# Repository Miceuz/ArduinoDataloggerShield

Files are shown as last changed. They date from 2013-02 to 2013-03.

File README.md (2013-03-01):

ArduinoDataloggerShield
=======================

SD card datalogger shield for Arduino with two external voltage references. 

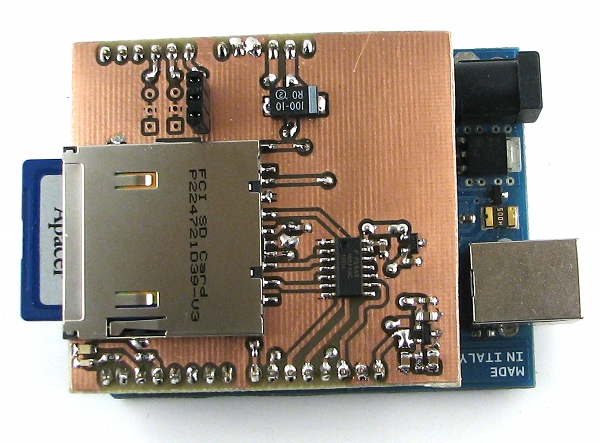
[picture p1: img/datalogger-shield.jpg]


I've made this shield because there were no designs in the wild employing external references - this is usefull feature to have when logging analog voltages.

Features: 
 * 74hc125 buffer for level translation
 * 1.20V voltage reference selectable via solder jumper
 * 2.5V voltage reference selectable via solder jumper
 * red indication led
 * green indication led
 * SD card detection
 * SD card write protection detection

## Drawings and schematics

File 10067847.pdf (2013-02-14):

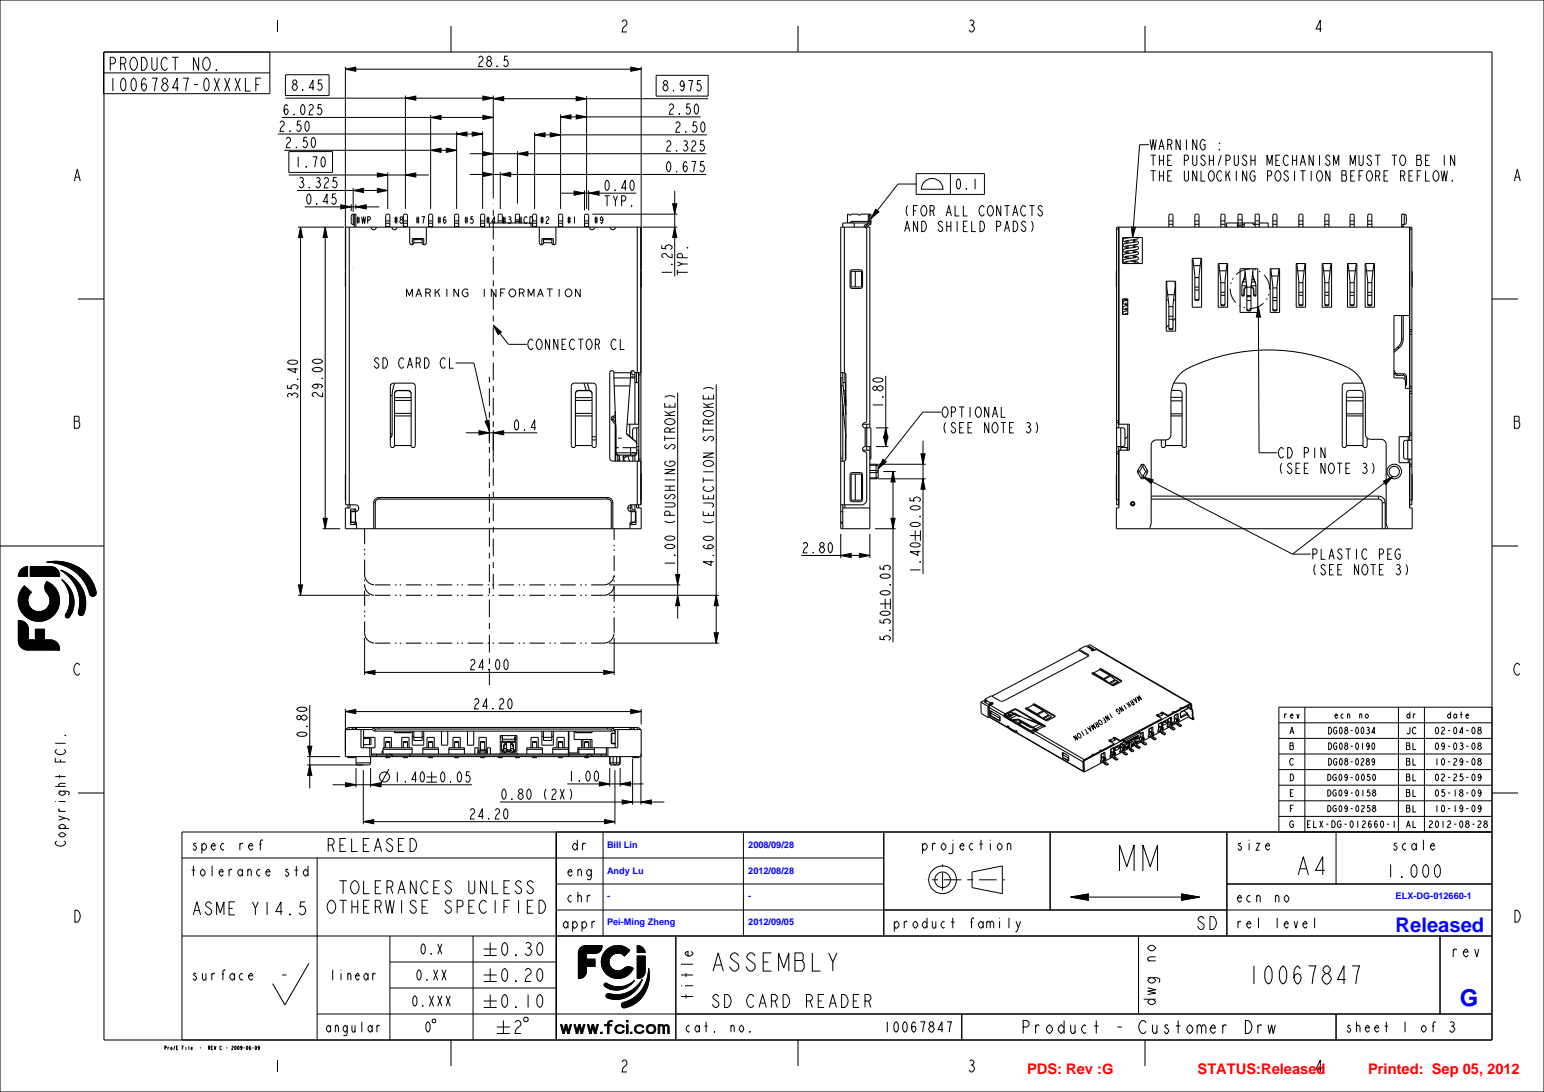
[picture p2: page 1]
Andy Lu; Bill Lin; Released; PDS: Rev :G; STATUS:Released; Printed: Sep 05, 2012

- | | | ELX-DG-012660-1

Pei-Ming Zheng | 2012/09/05

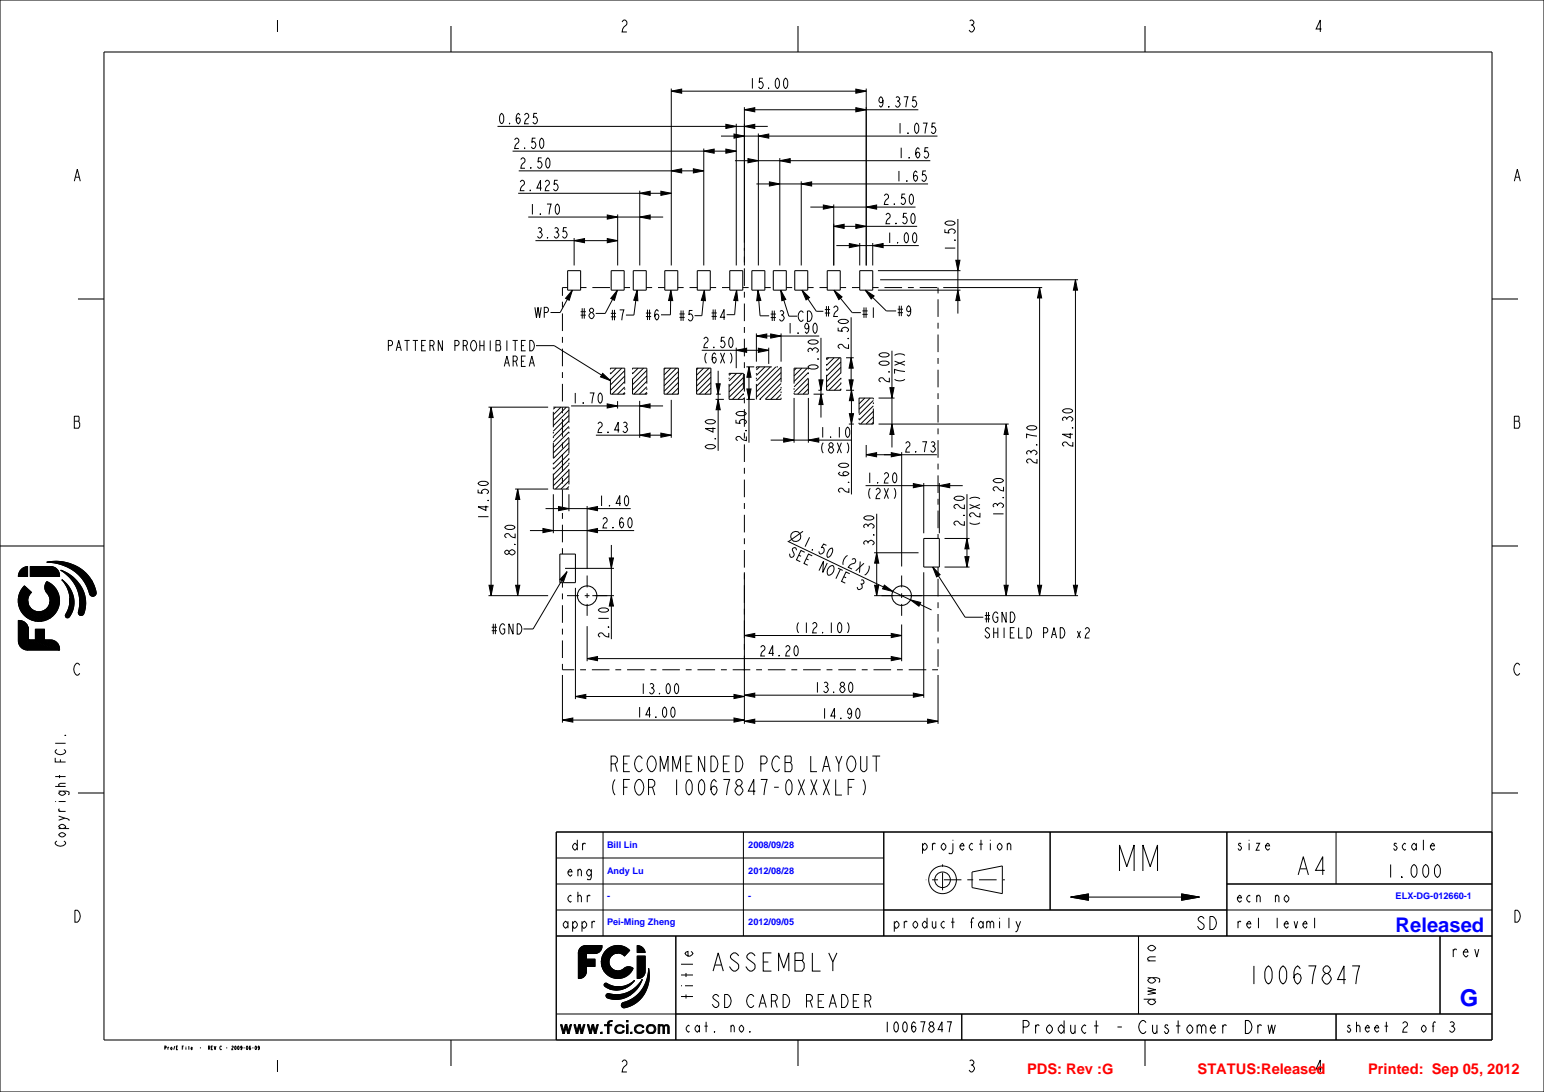
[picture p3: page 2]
Andy Lu; Bill Lin; Released

- | | | | ELX-DG-012660-1

Pei-Ming Zheng | 2012/09/05

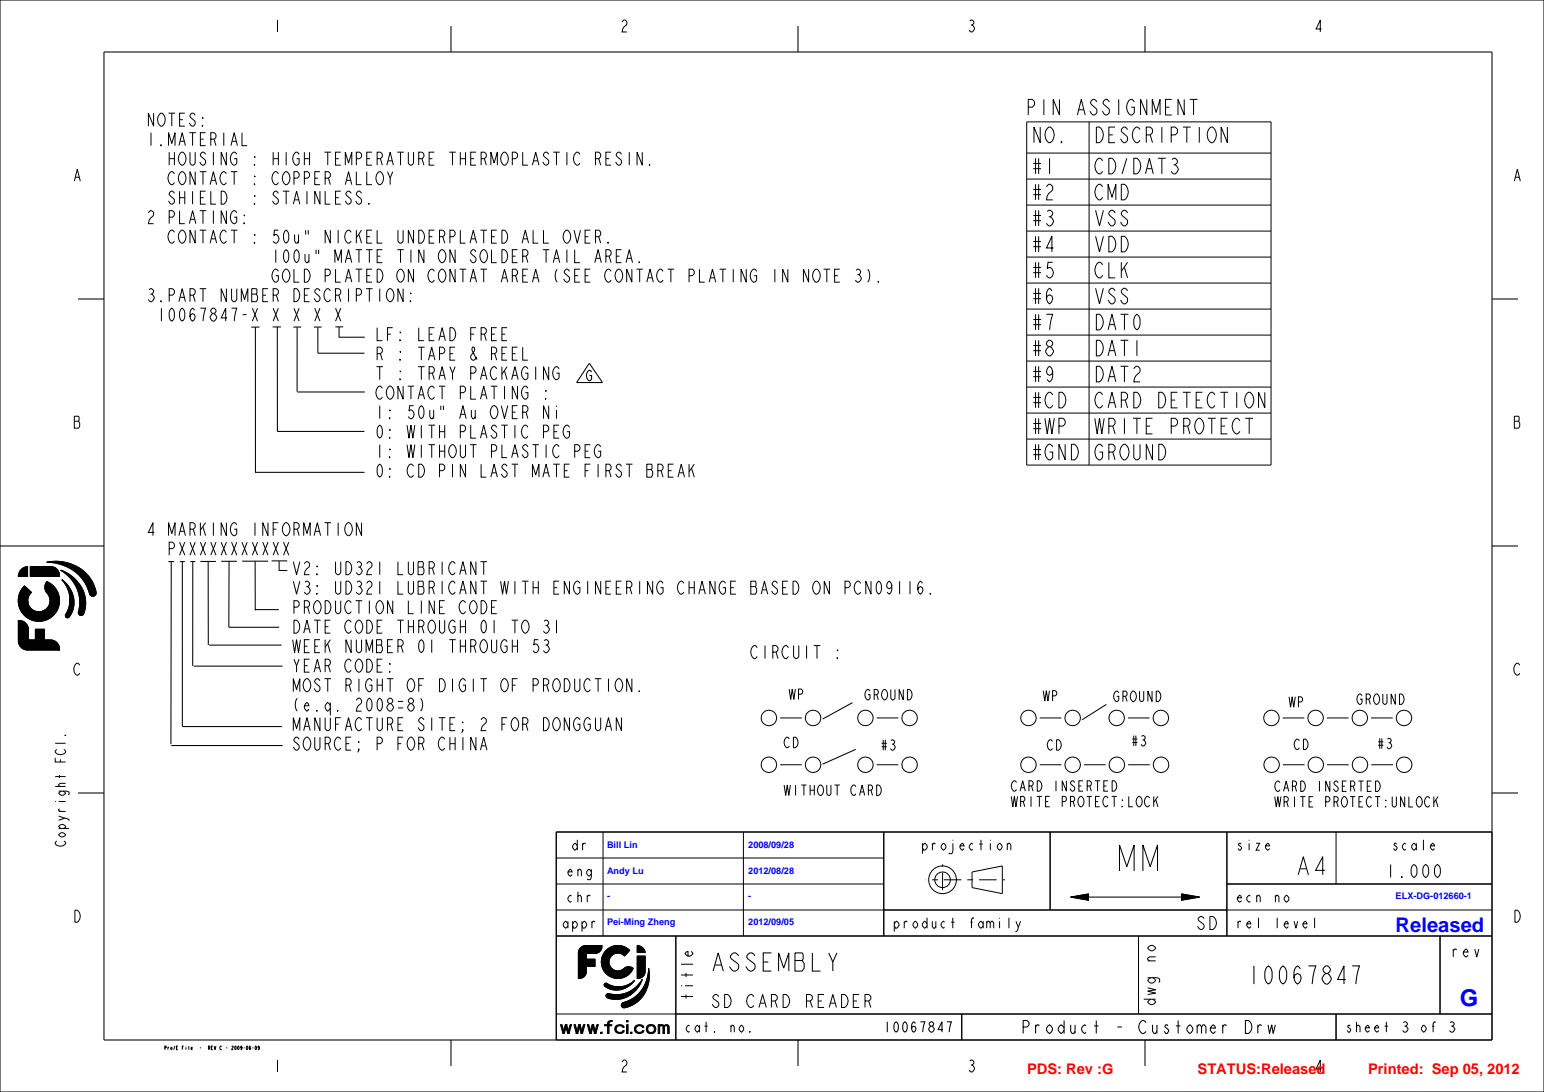
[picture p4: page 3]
Andy Lu; Bill Lin; Released

- | | | | ELX-DG-012660-1

Pei-Ming Zheng | 2012/09/05

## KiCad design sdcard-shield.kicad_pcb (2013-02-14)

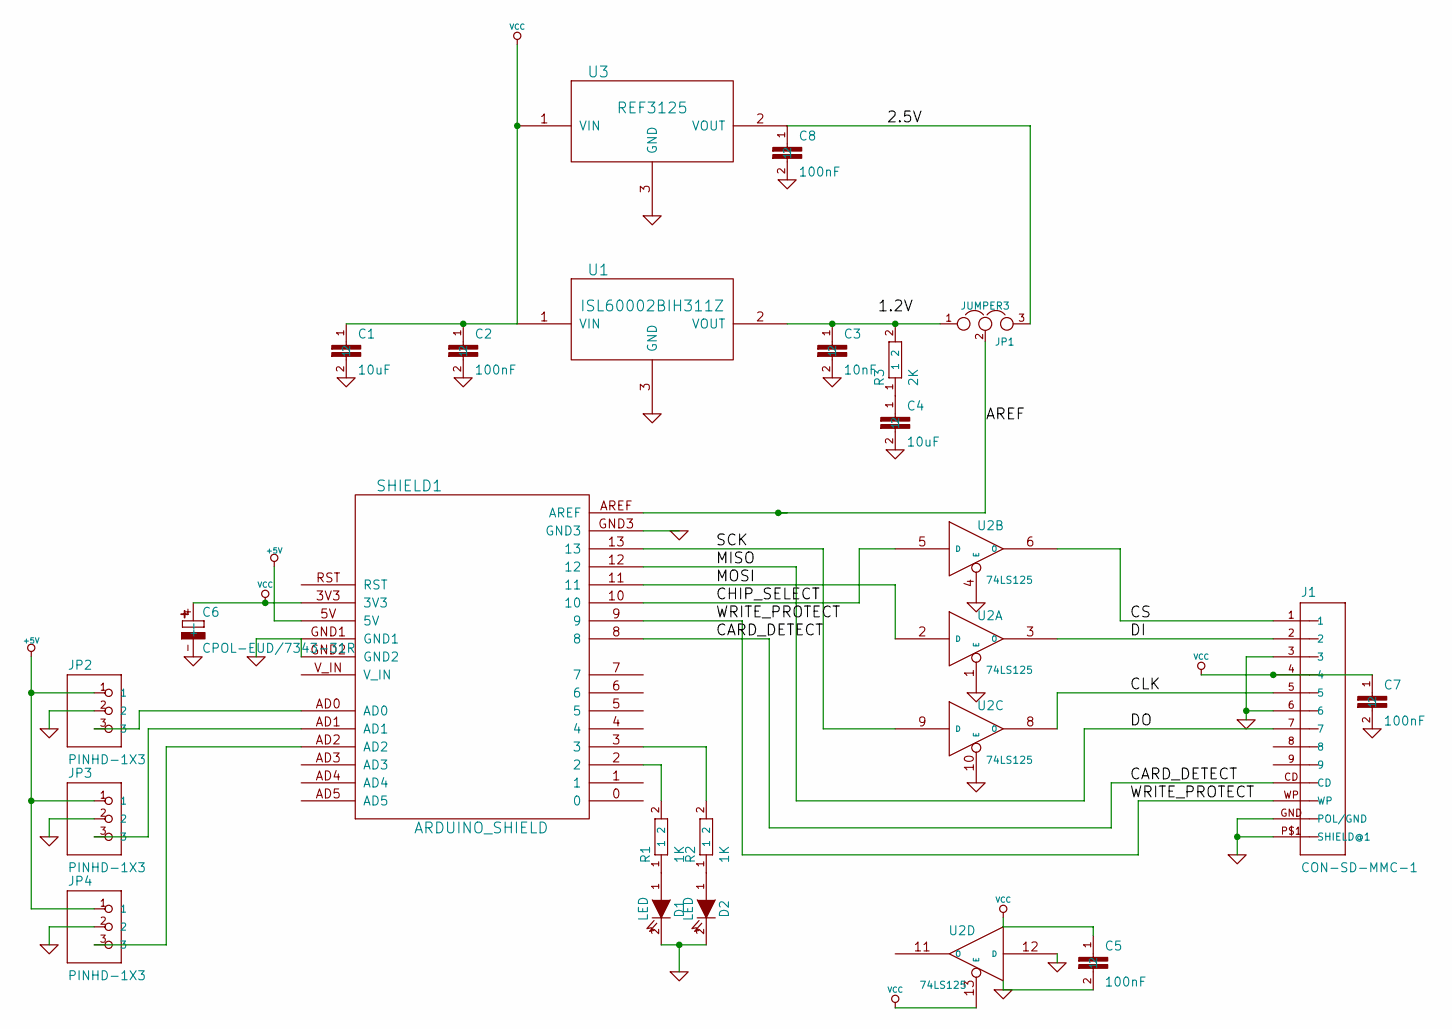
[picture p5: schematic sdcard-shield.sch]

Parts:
C1, C4: 10uF; rcl-C0805
C2, C5, C7, C8: 100nF; rcl-C0603
C3: 10nF; rcl-C0603
C6: CPOL-EUD/7343-31R; rcl-D/7343-31R
D1, D2: LED
J1: CON-SD-MMC-1; m-pad-2.1-14-5638-009-511-862
JP1: JUMPER3
JP2, JP3, JP4: PINHD-1X3; pinhead-1X03
R1, R2: 1K; rcl-R0603
R3: 2K; rcl-R0603
SHIELD1: ARDUINO_SHIELD
U1: ISL60002BIH311Z
U2: 74LS125
U3: REF3125; sot23

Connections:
+5V: JP2.1, JP3.1, JP4.1, SHIELD1.5V
/2.5V: C8.1, JP1.3, U3.2 (VOUT)
/AREF: JP1.2, SHIELD1.AREF
/CARD_DETECT: J1.CD, SHIELD1.8
/CHIP_SELECT: SHIELD1.10, U2.5 (D)
/CLK: J1.5, U2.8 (O)
/CS: J1.1, U2.6 (O)
/DI: J1.2, U2.3 (O)
/DO: J1.7, SHIELD1.12
/MOSI: SHIELD1.11, U2.2 (D)
/SCK: SHIELD1.13, U2.9 (D)
/WRITE_PROTECT: J1.WP, SHIELD1.9
GND: C1.2, C2.2, C3.2, C4.2, C5.2, C6.-, C7.2, C8.2, D1.2 (K), D2.2 (K), J1.3, J1.6, J1.GND (POL/GND), J1.P$1 (SHIELD@1), JP2.2, JP3.2, JP4.2, SHIELD1.GND1, SHIELD1.GND2, SHIELD1.GND3, U1.3 (GND), U2.1 (E), U2.4 (E), U2.7 (GND), U2.10 (E), U2.12 (D), U3.3 (GND)
unnamed: C3.1, JP1.1, R3.2, U1.2 (VOUT)
unnamed: C4.1, R3.1
unnamed: D2.1 (A), R2.1
unnamed: D1.1 (A), R1.1
unnamed: R2.2, SHIELD1.3
unnamed: R1.2, SHIELD1.2
unnamed: JP4.3, SHIELD1.AD2
unnamed: JP3.3, SHIELD1.AD1
unnamed: JP2.3, SHIELD1.AD0
VCC: C1.1, C2.1, C5.1, C6.+, C7.1, J1.4, SHIELD1.3V3, U1.1 (VIN), U2.13 (E), U2.14 (VCC), U3.1 (VIN)

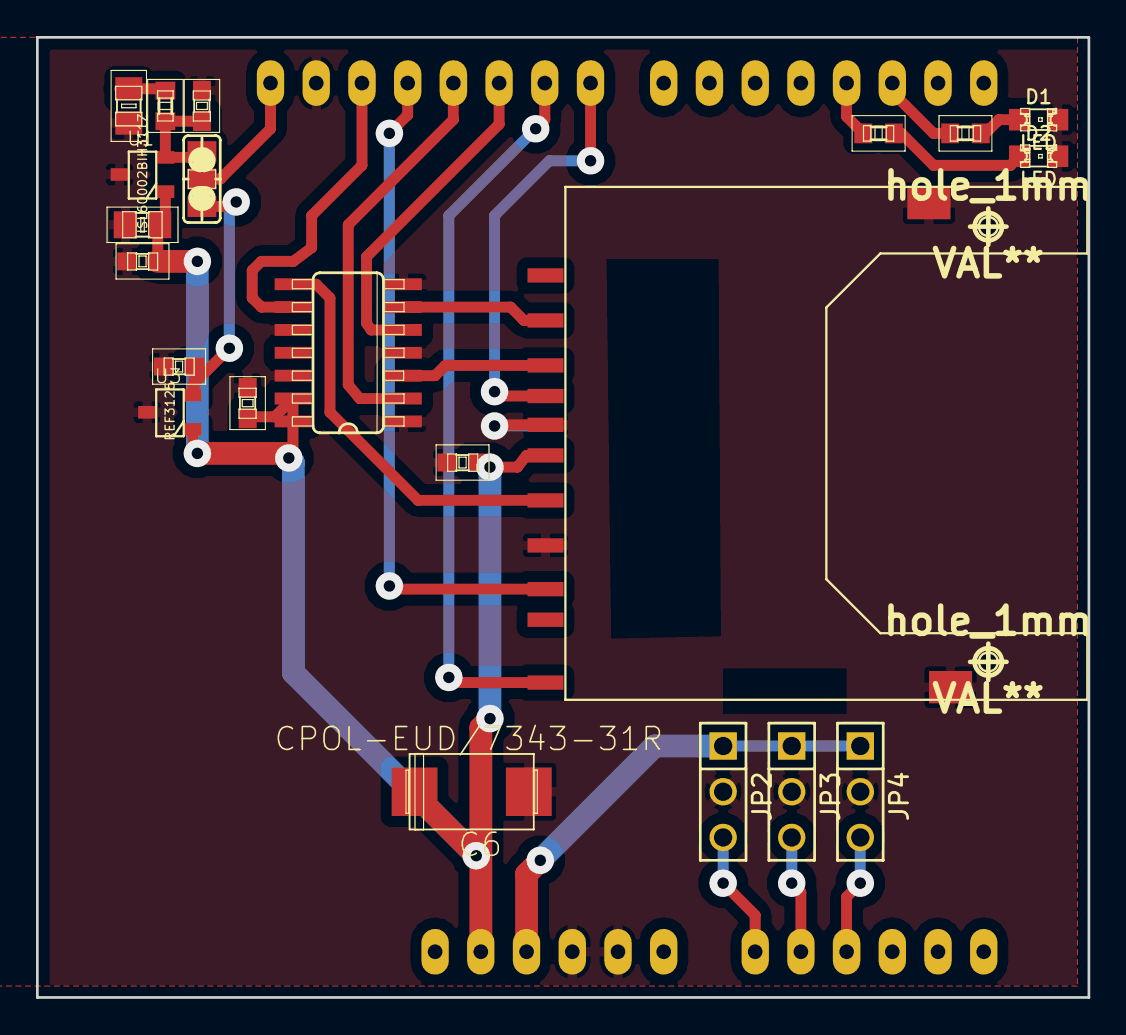
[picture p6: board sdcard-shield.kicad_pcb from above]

Board: 2 copper layers, 58.4 x 53.3 mm, 24 parts (0 on the bottom side), 23 nets.

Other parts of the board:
hole_1mm, hole_1mm#2: VAL**; hole_1mm

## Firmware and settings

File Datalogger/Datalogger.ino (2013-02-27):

/**
 *
 * 
 *
**/

#include <SD.h>

#define ERROR_LED 2
#define STATUS_LED 3
#define CS 10
#define CARD_DETECT 8
#define WRITE_PROTECTION 9

char outputFileName[10];
boolean wasError = false;
String content;

void blinkSDCardGood();

void setup() {
 analogReference(EXTERNAL);
 Serial.begin(9600);
 setupIO();
 setupSDCard(); 
 content = String("");
 content.reserve(16);
}

boolean cardPresentWriteable() {
  pinMode(CARD_DETECT, INPUT);
  digitalWrite(CARD_DETECT, HIGH);
  pinMode(WRITE_PROTECTION, INPUT);
  digitalWrite(WRITE_PROTECTION, HIGH);
  boolean ret = digitalRead(CARD_DETECT) || digitalRead(WRITE_PROTECTION);
  digitalWrite(CARD_DETECT, LOW);
  digitalWrite(WRITE_PROTECTION, LOW);
  pinMode(CARD_DETECT, OUTPUT);
  pinMode(WRITE_PROTECTION, OUTPUT);
  return ret;
}

void loop() {
  if(cardPresentWriteable()) {
    setError();
    delay(500);
  } else {
    if(wasError) {
      delay(500);
      digitalWrite(ERROR_LED, LOW);
      Serial.println("Reinitialising card...");

      if(setupSDCard()) {
        wasError = false;
      }
    } else {
      File outputFile = SD.open(outputFileName, FILE_WRITE);
      if(outputFile) {
        digitalWrite(STATUS_LED, HIGH);
        outputFile.println(getContent());
        outputFile.close();
        digitalWrite(STATUS_LED, LOW);
        delay(1000);
      } else {
        setError();
      }
    }
  }
}
  

String getContent() {
  content = "";
  content.concat(map(analogRead(A0), 0, 1023, 0, 2500));
  content.concat(", ");
  content.concat(map(analogRead(A1), 0, 1023, 0, 2500));
  content.concat(", ");
  content.concat(map(analogRead(A2), 0, 1023, 0, 2500));
  Serial.println(content);
  return content;
}

void setupIO() {
 pinMode(CS, OUTPUT);
 pinMode(ERROR_LED, OUTPUT);
 pinMode(STATUS_LED, OUTPUT);
}

boolean setupSDCard() {
 if(!SD.begin(CS)) {
   setError();
   Serial.println("Could not initialize card!");
 } else {
   Serial.println("SD card initialized.");
   if(setupOutputFile()) {
     blinkSDCardGood();
     return true;
   }
 }
}

boolean findFreeFileName() {
  unsigned int i = 1;
  char fileNameChar[10];
  boolean loopFileNames = true;
  String fileName;
  while(loopFileNames) {
    fileName = String("") + i + ".txt";
    Serial.print("Trying output file name ");
    fileName.toCharArray(fileNameChar, 9);
    Serial.print(fileNameChar);
    if(SD.exists(fileNameChar)) {
      Serial.println(" - already exists");
      i++;
      if(0 == i) {
        Serial.println("ERROR: Could not find a name for a new file. All 65535 filenames are taken. Clean up your SD card.");
        setError();
        return false;
      }
    } else {
      Serial.println(" - available");
      fileName.toCharArray(outputFileName, 9);
      loopFileNames = false;
    }
  }
  return true;
}

boolean setupOutputFile() {
  if(!findFreeFileName()) {
    return false;
  }
  File outputFile = SD.open(outputFileName, FILE_WRITE);
  if(!outputFile) {
    Serial.print("Failed to create file ");
    Serial.println(outputFileName);
    Serial.println("giving up");
    setError();
    return false;
  } else {
    outputFile.close();
    Serial.print("Logging to file ");
    Serial.println(outputFileName);
  }
  return true;
}

void blinkSDCardGood() {
   digitalWrite(ERROR_LED, LOW);
   digitalWrite(STATUS_LED, HIGH);
   delay(100);
   digitalWrite(STATUS_LED, LOW);
   delay(100);
   digitalWrite(STATUS_LED, HIGH);
   delay(100);
   digitalWrite(STATUS_LED, LOW);
}

void setError() {
   wasError = true;
   digitalWrite(ERROR_LED, HIGH);
}
